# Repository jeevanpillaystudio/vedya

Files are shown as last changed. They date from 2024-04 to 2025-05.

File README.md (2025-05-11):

# Vedya Design System

A generative design system for creating and fabricating geometric patterns and modular structures with computational methods in Fusion 360.

## Overview

**Project:** Mandala Sculpture for Australia Bush Festival  
**Materials:** Wood (Huon Pine), Modelling Paste, 3D Print Materials, CNC Router Materials  
**Dimensions:** Full Installation 2m x 2m; Prototypes vary in size

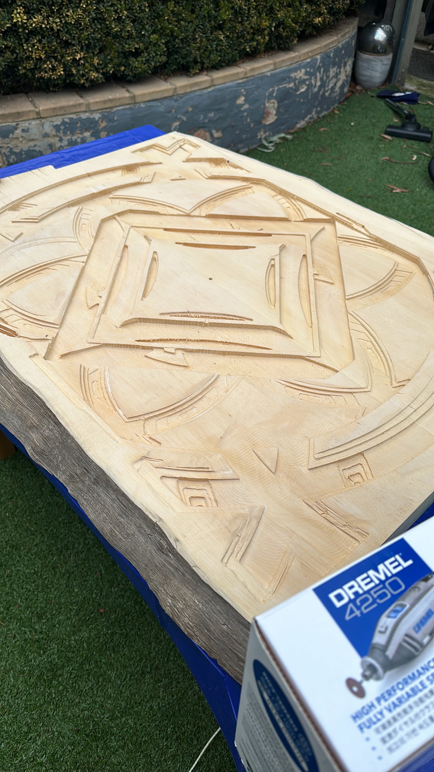
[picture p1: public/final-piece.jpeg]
Vedya Prototype

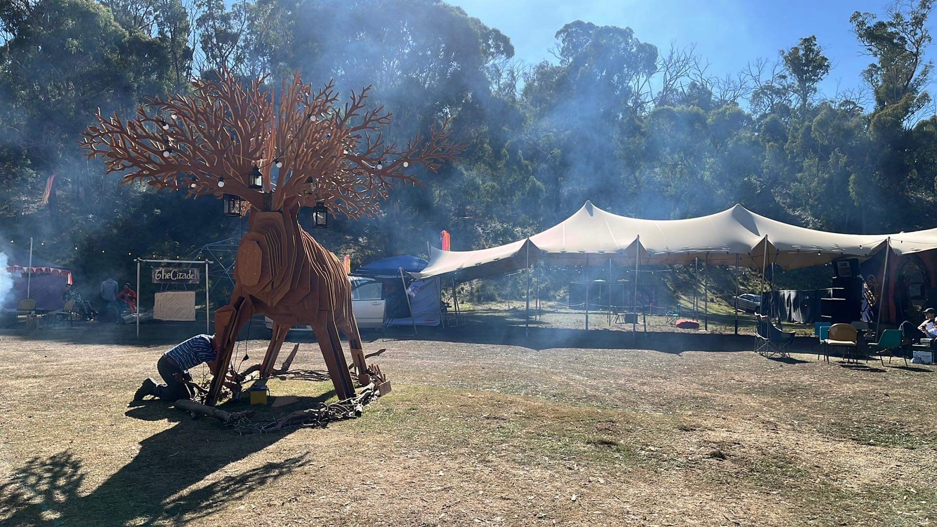
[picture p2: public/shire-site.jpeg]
Vedya on-site


## Visual Examples

### Fabrication Process
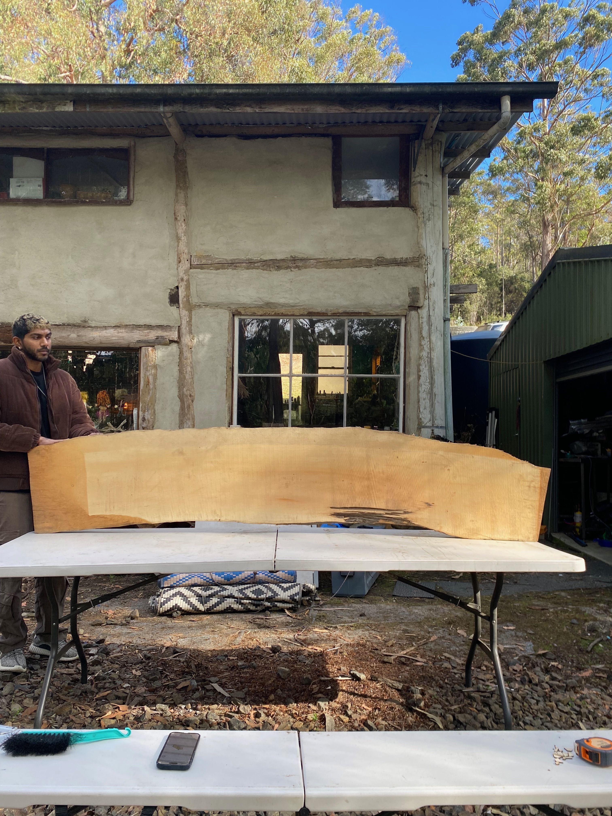
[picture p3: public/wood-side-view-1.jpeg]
Wood Source Material

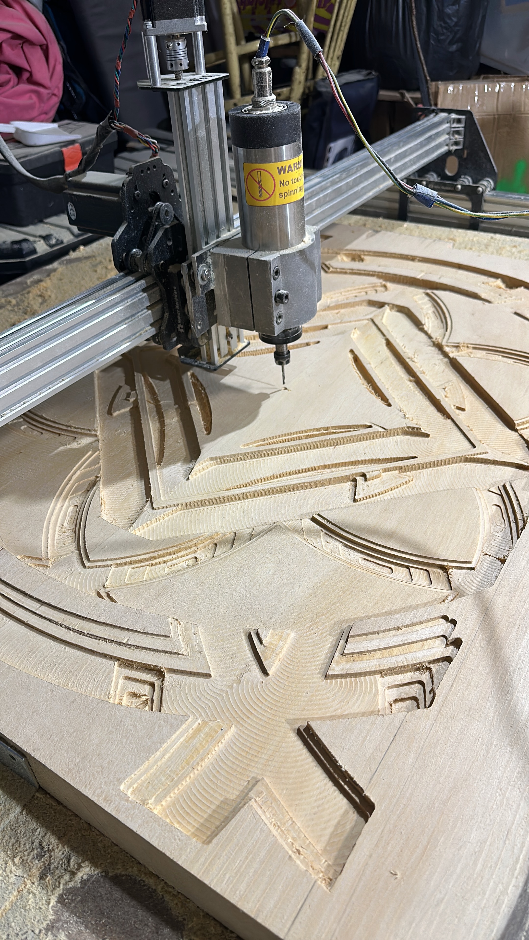
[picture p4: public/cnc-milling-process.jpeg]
CNC Milling Process


## Algorithm & Design Approach

The Vedya system uses a hierarchical composition-based algorithm to generate complex geometric designs:

### Core Algorithm

```
FUNCTION GenerateVedyaDesign(designType, seed, fabricationType, fabricationMode):
    // Initialize design context
    context = CreateDesignContext(designType, seed, fabricationType, fabricationMode)
    
    // Generate base geometry based on selected design template
    component = GenerateShireDesign(context.rootComponent)
    
    // Apply post-processing based on fabrication mode
    IF fabricationMode == "slicer":
        SliceComponent(component, layerDepth, layerCount)
    ELSE IF fabricationMode == "aggregator":
        AggregateComponents(component)
    
    RETURN component
```

### Composition System

The design generation uses a composition-based approach:

1. **Primitive Shapes**: Basic geometric elements (circles, rectangles)
2. **Modifiers**: Operations applied to shapes (extrude, boolean, array)
3. **Composition Layers**: Collections of shapes with modifiers
4. **Full Composition**: Hierarchical arrangement of layers

Example of the Shire design generation:

```
FUNCTION GenerateShireDesign(rootComponent):
    // Create background layer
    background = CreateBackgroundLayer(rootComponent)
    
    // Create border
    border = CreateBorder(rootComponent)
    
    // Create seed of life patterns (layered)
    seedOfLifeLayer0 = CreateSeedOfLifeLayer0(rootComponent)
    seedOfLifeLayer1 = CreateSeedOfLifeLayer1(rootComponent)
    seedOfLifeLayer2 = CreateSeedOfLifeLayer2(rootComponent)
    
    // Create core component
    core = CreateComponentCore(rootComponent)
    
    // Create torus astroid pattern
    torusAstroid = CreateTorusAstroid(rootComponent)
    
    // Apply middle cut
    ApplyMiddleCut(rootComponent)
    
    // Apply terrain cut (optional)
    ApplyTerrainCut(rootComponent)
    
    RETURN rootComponent
```

### Key Geometric Algorithms

#### Astroid Curve Algorithm

An astroid is a hypocycloid with four cusps. In the Vedya system, we implement a generalized version that allows for variable cusps (n-cusps) and parametric control. The algorithm to generate points along an astroid curve is:

```
FUNCTION GenerateAstroidPoints(centerX, centerY, radius, n, numPoints):
    points = []
    
    // Generate points along the astroid curve
    FOR i = 0 TO numPoints-1:
        t = i * (2π/numPoints)
        x = centerX + radius * cos(t)^n
        y = centerY + radius * sin(t)^n
        points.ADD((x, y))
    
    RETURN points
```

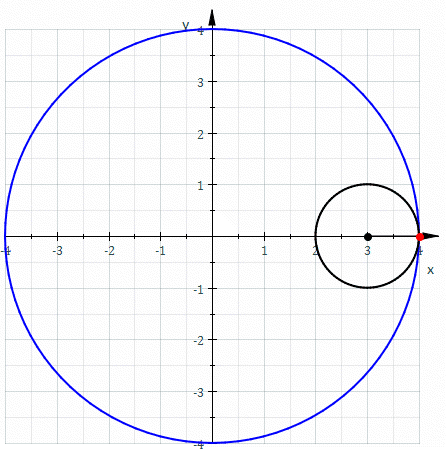
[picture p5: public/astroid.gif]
Astroid Curve Pattern


Where:
- `n` is the power parameter that controls the shape (n=3 for classic astroid)
- `numPoints` determines the resolution of the curve
- `radius` controls the size of the astroid

The Torus Astroid in the Vedya system combines this curve with circular elements to create complex patterns with:
- Inner and outer boundaries
- Stroke weight variations
- Radial symmetry
- Depth variations when extruded to 3D

#### Seed of Life Algorithm

The Seed of Life is a sacred geometry pattern formed by seven overlapping circles of the same size. The algorithm to generate this pattern follows these steps:

```
FUNCTION GenerateSeedOfLife(centerX, centerY, radius):
    // Create the central circle
    circles = [Circle(centerX, centerY, radius)]
    
    // Create six circles around the central circle
    FOR i = 0 TO 5:
        angle = i * (2π/6)
        newCenterX = centerX + radius * cos(angle)
        newCenterY = centerY + radius * sin(angle)
        circles.ADD(Circle(newCenterX, newCenterY, radius))
    
    RETURN circles
```

The Seed of Life pattern has deep historical significance in sacred geometry, appearing in ancient cultures worldwide. In the Vedya system, this pattern serves as a foundational element for creating complex mandala designs. The implementation allows for:

- Variable scaling of the pattern
- Layering with different radii
- Combination with other geometric elements through boolean operations
- Depth extrusion to create 3D forms

### Geometric Operations

The system uses several key geometric operations:

1. **Boolean Operations**: Union, difference, and intersection of shapes
2. **Array Patterns**: Radial, linear, and grid arrangements of elements
3. **Extrusion**: Converting 2D sketches to 3D forms
4. **Coordinate Transformations**: Mapping between coordinate systems (cartesian, cylindrical, spherical)

## Architecture

The Vedya system follows a pattern → transform → render workflow:
- **Pattern:** Generate base geometric patterns
- **Transform:** Apply coordinate transformations (cartesian, cylindrical, spherical)
- **Render:** Output to various formats (STL, OBJ, PNG)

## Setup & Installation

### Fusion 360 Integration

1. Configure environment:
   ```
   # In .env file
   PYTHONPATH=/path/to/fusion360/API/Python/libs
   LOGFILEPATH=/path/to/logfile.txt
   ```

2. Run the script:
   - Open Fusion 360
   - Open the script in Script Editor
   - Run the script

### Python Development

1. Setup environment:
   ```
   poetry shell
   poetry install
   ```

2. Available commands:
   ```
   # Transform coordinates
   vedya transform input.txt --target cylinder --resolution 0.1 --length 10 --height 4 --radius 1 --output output.txt
   
   # Render output
   vedya render output.txt --output output.stl --color grayscale
   
   # Run examples
   vedya example output_path
   ```

## Fabrication Methods

### 3D Printing
- **Printers:** Bambu Labs X1C/P1S (256mm³ build volume)
- **Materials:** PLA, PETG, TPU, ABS, ASA, PVA, PET
- **Examples:**
  - [Print 1 with Kailash Terrain](public/3d-printer-prototypes/print-1/3d-vedya-print-with-kailash-0.75;1;8.mp4)
  - [Print 2 Standard](public/3d-printer-prototypes/print-2/3d-vedya-print-1;1;8.mp4)
  - [Detailed Print Process](src/public/videos/detailed-print-process.mov)

### CNC Milling
- Used for wood components (Huon Pine)
- [Laser Prototype Slice](public/laser-prototypes/vedya-laser-1/slice-body-8/slice-body-8.stl)
- [CNC Toolpath Simulation](src/public/videos/cnc-toolpath-simulation.mov)

### Terrain Models
- [Low Resolution Kailash](public/low-res-kailash/low-res-kailash.stl)
- [Medium Resolution Kailash](public/mid-res-kailash/mid-res-kailash.stl)
- [Terrain Integration Process](public/terrain-integration.png)

## Project Components

### Shire
Mandala design for Australia Bush Festival, collaboration between Jeevan Pillay and Adam Brown, Gemma & team at Tasmania.
- Implementation: [Shire Design](src/core/fabrication/design/shire/index.py)
- [Installation Photos](public/shire-site.jpeg)

## Documentation

Additional documentation available in subdirectories:
- [Core Library Documentation](src/lib/README.md)
- [Print 1 Notes](public/3d-printer-prototypes/print-1/README.md)
- [Print 2 Notes](public/3d-printer-prototypes/print-2/README.md)

## Troubleshooting

- [Fixing VSCode x Python Code Hints](https://forums.autodesk.com/t5/fusion-api-and-scripts/code-hints-in-visual-studio-code-howto/td-p/9151250)
- [BambuStudio Filament Process](public/3d-printer-prototypes/README.md)

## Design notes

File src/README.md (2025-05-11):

# API Vedya Draw

A Fusion 360 add-in for generating parametric and direct designs using the Vedya design system.

## Overview

This add-in provides tools for creating generative designs within Fusion 360, with a focus on:
- Mandala-like patterns
- Modular storage systems (UMSS)
- Architectural models (Parthenon)

## Installation

1. Clone this repository to your local machine
2. In Fusion 360, go to **Scripts and Add-Ins** (Shift+S)
3. Click the green "+" icon next to "My Scripts"
4. Navigate to the cloned repository and select the `src` folder
5. Click "Run" to execute the script

## Configuration

### VSCode Setup

1. Install recommended extensions:
   - ms-python.black-formatter
   - ms-python.vscode-pylance

2. Configure Python paths in `.vscode/settings.json`:
   ```json
   "python.autoComplete.extraPaths": [
       "/path/to/Autodesk/Autodesk Fusion 360/API/Python/defs"
   ],
   "python.analysis.extraPaths": [
       "/path/to/Autodesk/Autodesk Fusion 360/API/Python/defs"
   ]
   ```

3. Set up debugging in `.vscode/launch.json`

## Project Structure

- `APIDrawVedya.py` - Main entry point for the Fusion 360 add-in
- `APIDrawVedya.manifest` - Add-in manifest file
- `__main__.py` - Standalone execution entry point
- `/core` - Core functionality
  - `/context.py` - Fusion 360 design context
  - `/types.py` - Type definitions
  - `/utils.py` - Utility functions
  - `/geometry` - Geometric primitives and operations
  - `/fabrication` - Fabrication-specific code
    - `/design` - Design templates
      - `/umss` - Universal Modular Storage System
      - `/parthenon` - Parthenon architectural model
      - `/shire` - Shire festival installation
- `/lib` - Standalone Python library for coordinate transformations and rendering

## Usage

The add-in creates designs based on the selected fabrication type and mode:

```python
# Example from APIDrawVedya.py
context = FusionDesignContext(
    app_context=adsk.core.Application.get(),
    design_type=DesignType.DIRECT,
    seed=create_seed(),
    fabrication_type=FabricationType.CNC_MILL,
    fabrication_mode=FabricationMode.NORMAL,
)

# Generate the design
start_func(root_component)
```

## Fabrication Types

- `CNC_MILL` - For CNC milling operations
- `PRINT_3D` - For 3D printing
- `LASER_CUT` - For laser cutting

## Fabrication Modes

- `NORMAL` - Standard design generation
- `SLICER` - Generates sliced layers for fabrication
- `AGGREGATOR` - Combines multiple components

## Examples

### UMSS (Universal Modular Storage System)

The UMSS is a modular storage system designed for 3D printing:
- Based on 128mm x 128mm tiles
- Uses CA007 (6x3mm) and CA008 (8x3mm) magnets
- Includes female/male tile pairs

See [UMSS Design](./core/fabrication/design/umss/index.py) for implementation details.

### Shire Festival Installation

A mandala-like design for the Shire festival in Victoria, Melbourne:
- Collaboration with Adam Brown, Gemma & team in Tasmania
- Uses Huon Pine wood
- Generated using a specific seed for consistency

See [Shire Design](./core/fabrication/design/shire/index.py) for implementation details.

## Library Tools

The `lib` directory contains standalone Python tools for:
- Coordinate transformations (cartesian, cylindrical, spherical)
- Rendering outputs to various formats
- Example generators

See [Library Documentation](./lib/README.md) for more details.

## Troubleshooting

1. [Fixing VSCode x Python Code Hints](https://forums.autodesk.com/t5/fusion-api-and-scripts/code-hints-in-visual-studio-code-howto/td-p/9151250)
2. If you encounter errors with Python paths, ensure your `.vscode/settings.json` points to the correct Fusion 360 API location
3. For logging issues, check the `logfile.txt` in the add-in directory

## Resources

- [Fusion 360 API Documentation](https://help.autodesk.com/view/fusion360/ENU/?guid=GUID-7B5A90C8-E94C-48DA-B16B-430729B734DC)
- [Python API Reference](https://help.autodesk.com/view/fusion360/ENU/?guid=GUID-9BAACC99-6666-4210-9F52-36D6A3275E5B)
- [3D Printing Prototypes](../public/README.md)

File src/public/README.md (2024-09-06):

## 3D Printer Prototyping
#### Model

| Model | Material Supported | Bed Size | Printer Size | Support | Sound Levels (dB) |
| --- | --- | --- | --- | --- | --- |
| Bambu Labs X1C | PLA, PETG, TPU, ABS, ASA, PVA, PET | 256mm x 256mm x 256mm | 389mm x 389mm x 457mm | Concrete Slab (450mm x 450mm) - Soft Foam | |
| Bambu Labs P1S | PLA, PETG, TPU, PVA, PET, ABS, ASA | 256mm x 256mm x 256mm | 389mm x 389mm x 457mm | Concrete Slab (450mm x 450mm) - Soft Foam | |
> for knowledge base, head [here](https://wiki.bambulab.com/en/knowledge-sharing)

### UMSS Tiling

#### Milestone 1 - 6x3 N35 Magnet (without fillet)	
| Hole Radius (mm) | Fitting | Notes |
| --- | --- | --- |
| 0.30 | Tight | |
| 0.31 | Perfect | Slight force needed to push it in but fits in tightly. Removing magnet can be an issue though. |
| 0.32 | Slightly Loose | |
| 0.33 | Loose | |
| 0.34 | Loose | |
| 0.35 | Loose | |

#### Milestone 2 - 6x3 N35 Magnet with 0.31mm Hole (with fillet)	
| Fillet Size (mm) | Fitting | Notes |
| --- | --- | ----- |
| 1 | Perfect | |
| 1.25 | Perfect | |
| 1.5 | Slightly Loose | |
| 1.75 | Slightly Loose | |
| 2 | Slightly Loose | |
#### Milestone 3
> built grid of tiles; 5 by 5 with thickness of 1mm; r.e printed two version. 
> 1. full grid 5 by 5
> 2. only the corners (meaning a cut-out in the middle) - save material
#### Milestone 4
> built with wall thickness 1.28mm, outer wall thickness of 5mm (stroke-weight 1.28mm), inner cross-section wall of 4mm (stroke-weight 0.96mm)

#### Essentials
1. https://youtu.be/J_pxk7HP3RE?si=55Y-H1U8Oew2n4SE
2. [Concrete Slab + Foam Sound & Vibration Dampening](https://youtu.be/y08v6PY_7ak?si=_SXhxkkFH9TeksmH)

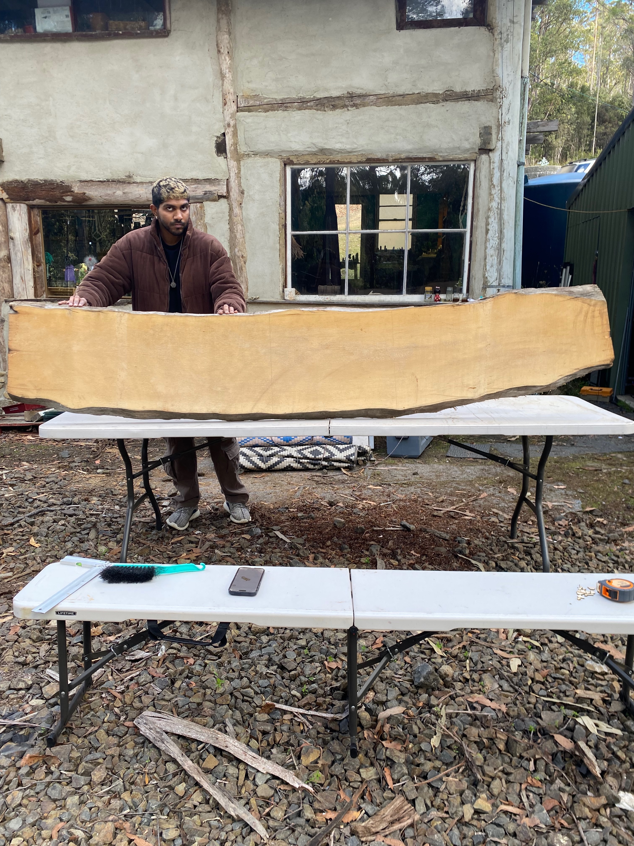
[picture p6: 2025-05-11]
public/wood-side-view-2.jpeg

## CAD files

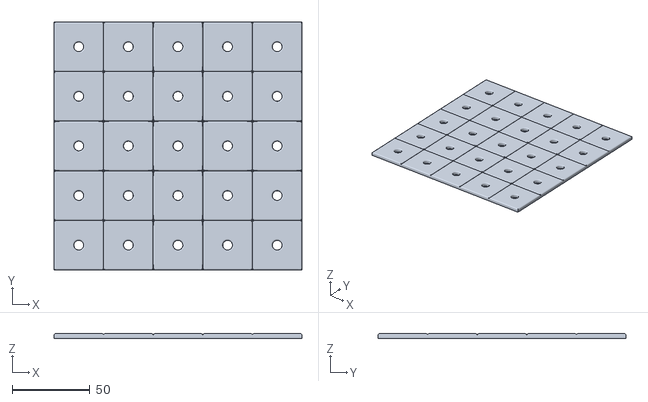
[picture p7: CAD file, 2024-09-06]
src/public/f360-milestone-3/5by5-full.stl
160.0 x 160.0 x 3.00

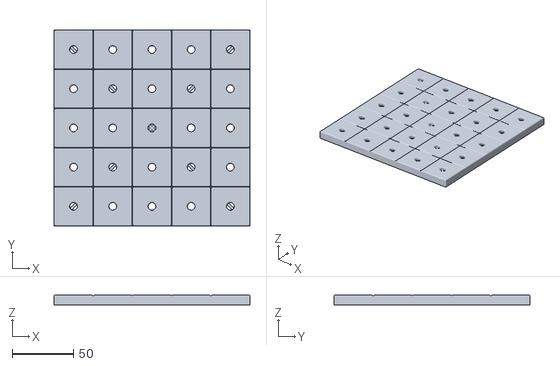
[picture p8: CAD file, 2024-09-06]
src/public/f360-milestone-4/5by5-full-with-brace.stl
160.0 x 160.0 x 8.00

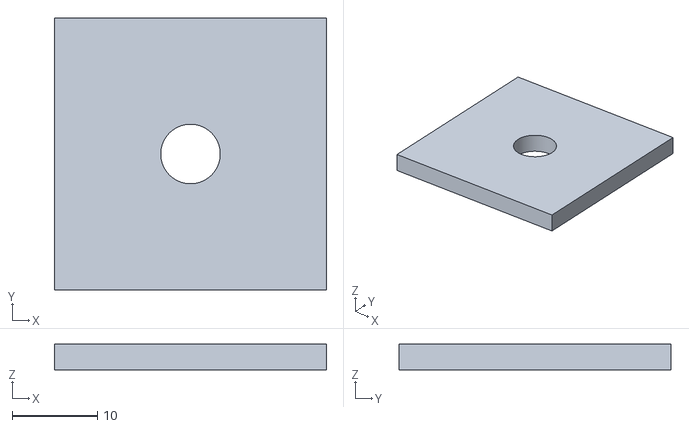
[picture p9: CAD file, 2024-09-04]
src/public/f360-milestone-1/tile-magnet-hole-radius-0.35mm.stl
32.0 x 32.0 x 3.00

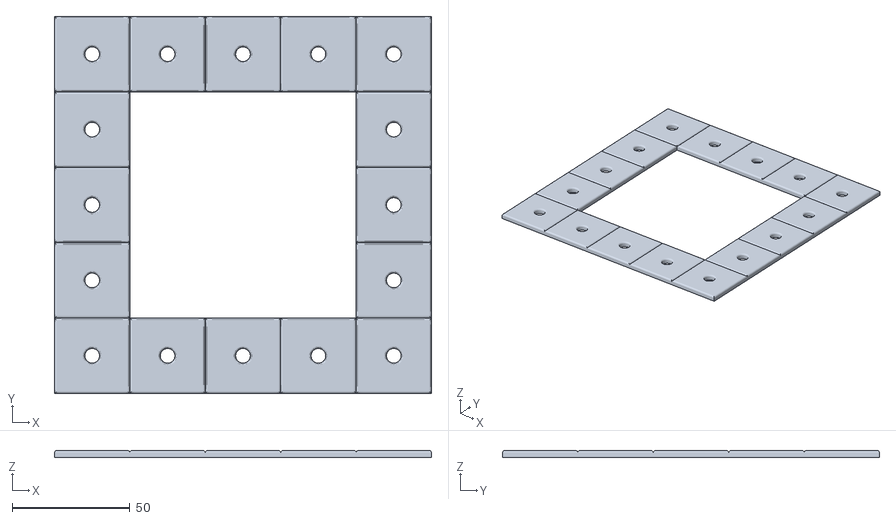
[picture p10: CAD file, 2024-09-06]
src/public/f360-milestone-3/5by5-only-corner.stl
160.0 x 160.0 x 3.00

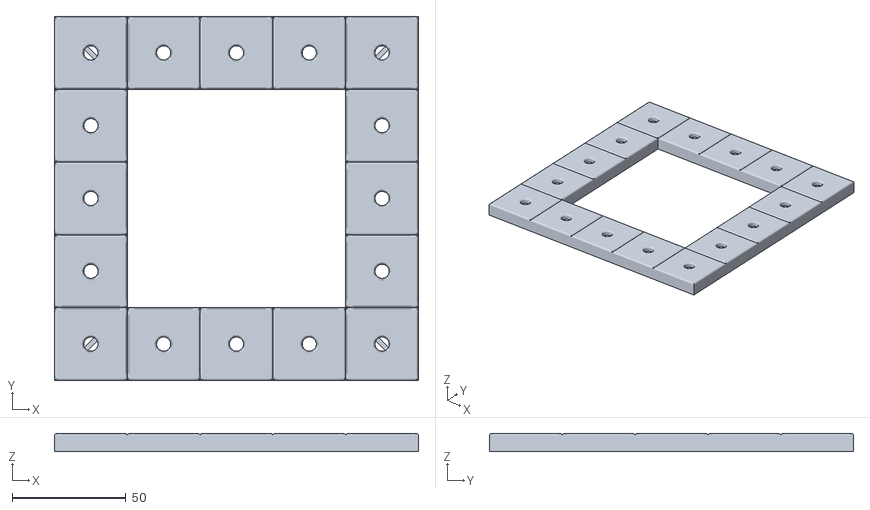
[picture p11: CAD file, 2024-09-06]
src/public/f360-milestone-4/5by5-only-corner-with-brace.stl
160.0 x 160.0 x 8.00

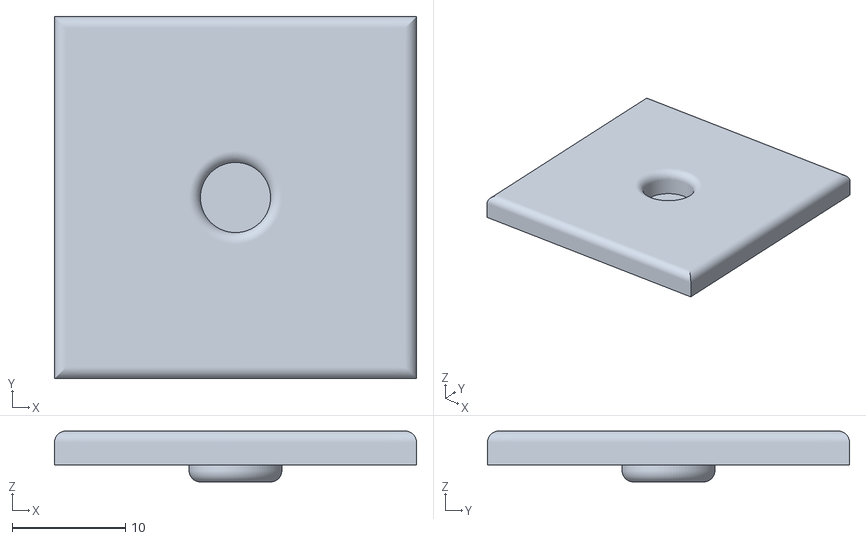
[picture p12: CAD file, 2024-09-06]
src/public/f360-milestone-5/magnet-base-ring-thickness-0.15mm.stl
32.0 x 32.0 x 4.50

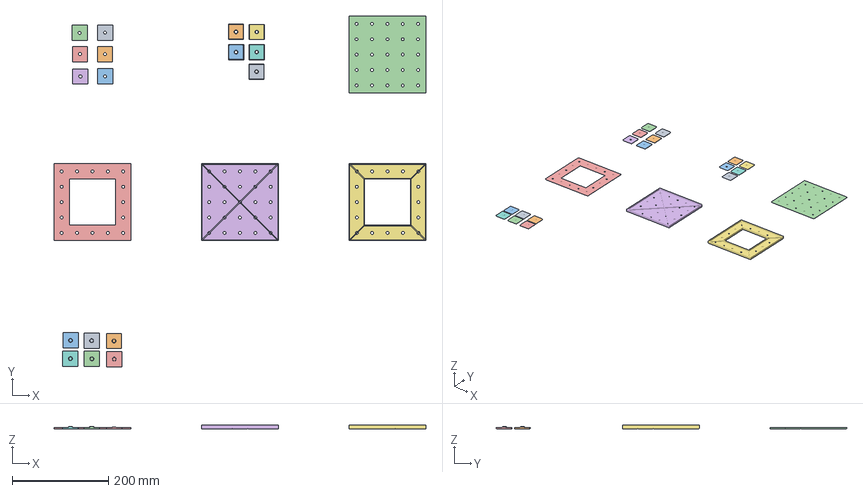
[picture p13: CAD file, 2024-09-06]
src/public/tile-magnet-hole-radius-0.30mm.3mf
774.2 x 729.7 x 8.00 mm
tile-magnet-hole-radius-0.30mm.stl
tile-magnet-hole-radius-0.31mm.stl
tile-magnet-hole-radius-0.32mm.stl
tile-magnet-hole-radius-0.33mm.stl
tile-magnet-hole-radius-0.34mm.stl
tile-magnet-hole-radius-0.35mm.stl
tile-magnet-fillet-1mm.stl
tile-magnet-fillet-1.25mm.stl
tile-magnet-fillet-1.5mm.stl
tile-magnet-fillet-1.75mm.stl
tile-magnet-fillet-2mm.stl
5by5-full.stl
5by5-only-corner.stl
5by5-full-with-brace.stl
5by5-only-corner-with-brace.stl
magnet-base-ring-thickness-0.25mm.stl x 2
magnet-base-ring-thickness-0.20mm.stl x 2
magnet-base-ring-thickness-0.15mm.stl x 2

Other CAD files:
public/3d-printer-prototypes/print-1/3d-vedya-print-0.75;1;8.3mf
public/3d-printer-prototypes/print-2/3d-vedya-print-1;1;8.3mf
public/laser-prototypes/vedya-laser-1/slice-body-4/slice-body-4.stl
public/laser-prototypes/vedya-laser-1/slice-body-5/slice-body-5.stl
public/laser-prototypes/vedya-laser-1/slice-body-6/slice-body-6.stl
public/laser-prototypes/vedya-laser-1/slice-body-7/slice-body-7.stl
public/laser-prototypes/vedya-laser-1/slice-body-8/slice-body-8.stl
public/laser-prototypes/vedya-laser-1/slice-body-9/slice-body-9.stl
public/low-res-kailash/low-res-kailash.stl
public/mid-res-kailash/med-res-kailash.obj
src/public/f360-milestone-2/tile-magnet-fillet-1mm.stl
public/3d-printer-prototypes/3d-print.f3d
public/3d-printer-prototypes/print-1/3d-vedya-print-0.75;1;8.stl
public/3d-printer-prototypes/print-1/3d-vedya-print-with-kailash-0.75;1;8.stl
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

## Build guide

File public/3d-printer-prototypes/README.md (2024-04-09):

### Helpers

1. Access BambuStudio Filament Process
    - /Users/[username]/Library/Application Support/BambuStudio/user

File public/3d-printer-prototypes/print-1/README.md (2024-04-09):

# Information

1. Failed due to wrong `wall generator` settings; `classic` was selected on Bambu Labs.
2. Kailash terrain printed decently.

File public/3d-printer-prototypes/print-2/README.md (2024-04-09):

# README

1. `Wall Geneator` settings; `arachne` was selected on Bambu Labs.

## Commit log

2024-04-03 added blender, stl & obj file
    [low-res-kailash.blend, low-res-kailash.obj, low-res-kailash.stl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]
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2024-04-08 added lfs & 3d-print-prototypes
    [3d-vedya-print-0.75;1;8.3mf, 3d-vedya-print-0.75;1;8.stl, 3d-vedya-print-with-kailash-0.75;1;8.stl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]
2024-04-08 added f3d main file
    [3d-print.f3d]
2024-04-09 added 3d printer mods folder
    [3d-print.f3d, 3d-vedya-print-0.75;1;8.3mf, 3d-vedya-print-0.75;1;8.stl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]
2024-04-09 added vedya print two, same issue; can see in bambu studio, slice plate only shows some parts of the print
    [3d-vedya-print-0.75;1;8.3mf, 3d-vedya-print-0.75;1;8.stl, 3d-vedya-print-with-kailash-0.75;1;8.stl]
2024-04-09 added print-2 details and updated README for print-1
    [3d-print.f3d, 3d-vedya-print-0.75;1;8.3mf, 3d-vedya-print-1;1;8.3mf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]
2024-04-09 added user profile
    [3d-vedya-print-1;1;8.3mf]
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2024-04-09 updated 3d-print.f3d
    [3d-print.f3d]
2024-04-09 added kailash print-2
    [3d-print.f3d, 3d-vedya-print-with-kailash-0.75;1;8.stl]
2024-04-09 added kailash to bambu studio
    [3d-vedya-print-1;1;8.3mf]
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2024-04-10 added torus
    [3d-vedya-print-1;1;8.3mf]
2024-04-10 added timer system & now instead of drawing many sketches, the body just gets copied and move
2024-04-10 reintroduced kailash cut on seed of life; not working
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2024-04-17 current version; kinda broken
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2024-04-17 added laser prototypes stl & dxf file (for lightburn)
    [slice-body-4.dxf, slice-body-4.stl, slice-body-5.dxf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]
2024-04-18 added lidar scan results of prototype wood
    [slice-body-4.dxf, slice-body-4.stl, slice-body-5.dxf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]
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2024-04-21 now sol generates first; issue with cut
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2024-06-08 now the full transformation of a circle to a cylinder has been written in matplotlib
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2024-07-17 added bse files for cylinder transform and openscad file gen
    [cylindrical_model.scad]
2024-07-17 fixed issue with coord-transform not running; the cylinder_resolution in __main__ was too high
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2024-07-18 created components that mimic cylinder & rectangles; being drawn out looking like wireframes using points & buffer
2024-07-20 now viewcube & stl objects moves together
    [teapot.stl]
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2024-08-19 moved vedya files to v1 folder
    [3d-print.f3d, 3d-vedya-print-0.75;1;8.3mf, 3d-vedya-print-0.75;1;8.stl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]
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2024-08-20 added kailash terrain cut to shire; not cutting due to area hard coded
2024-08-20 fixed all arguments in func to snake case
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2024-08-24 somewhat union & difference working; issue is that we only work on single BRepBody when sometimes there can be multiples after a cut
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2024-08-27 removed unused python related stuff
    [cylindrical_model.scad]
2024-08-27 created public fodler for v1
    [3d-print.f3d, 3d-vedya-print-0.75;1;8.3mf, 3d-vedya-print-0.75;1;8.stl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]
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2024-09-04 f360 milestone 1; raidius variation
    [tile-magnet-hole-radius-3.0.stl, tile-magnet-hole-radius-3.1.stl, tile-magnet-hole-radius-3.2.stl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]
2024-09-04 converted the magnet hole stl files to mm
    [tile-magnet-hole-radius-0.30mm.stl, tile-magnet-hole-radius-0.31mm.stl, tile-magnet-hole-radius-0.32mm.stl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]
2024-09-04 seems like 0.31mm is a perfect fit. but still slightly tight. now lets do testinggg on fillet
    [tile-magnet-hole-radius-0.30mm.3mf, tile-magnet-hole-radius-mm-test.3mf, tile-magnet-hole-radius-mm-test.f3d]
2024-09-06 added all milestone prints; 1 - 4
    [5by5-full-with-brace.stl, 5by5-full.stl, 5by5-only-corner-with-brace.stl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]
2024-09-06 added milestone 5
    [magnet-base-ring-thickness-0.15mm.stl, magnet-base-ring-thickness-0.20mm.stl, magnet-base-ring-thickness-0.25mm.stl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]
2025-05-11 removed all files related to the 3D printer prototypes and laser prototypes, including various STL, OBJ, and other format files, as well as associated README and configuration files
    [3d-print.f3d, 3d-vedya-print-0.75;1;8.3mf, 3d-vedya-print-0.75;1;8.stl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]
2026-10-14 Add the uv project scaffold
    The project metadata and tool configuration for the build123d rewrite:
    pyproject.toml (uv_build backend, dependencies, the render extra, ruff,
    pyright strict, pytest and coverage settings), a Makefile whose default
    target is `check`, pre-commit hooks that run ruff and `uv lock --check`
    through uv, an .editorconfig, a CI workflow with a lint job and a test
    matrix, Dependabot for uv and GitHub Actions, and a .gitignore cut down
    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
2026-10-14 Keep the checks off the Fusion 360 code until it leaves the tree
    The old script stays in src/ until its replacement passes, and nothing
    reads it from the working tree: the behaviour pin reads it from git
    history. Linting it would mean 474 ruff findings and 399 pyright errors
    in code that is about to go, and pre-commit's whitespace fixers would
    rewrite files, src/public/ among them, that are later moved by blob id.
    - ruff excludes the Fusion code, and force-exclude applies that to the
    files pre-commit names.
    - pyright checks src/vedya rather than all of src.
    - pre-commit skips src/ outside src/vedya, .vscode/ and .env.example.
    - The whitespace hook keeps Markdown's two-space line breaks.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
2026-10-14 Add the geometry, model and export layers of the vedya package
    The package starts as a uv project on Python 3.12, with the lock file
    and the `examples` extra (noise 1.2.2, for the flow field to come).
    - geometry: circle, rectangle and diamond regions; `stroke`, the band
    along an outline on the side `Align` names (INSIDE is Fusion's Side1),
    offset with sharp corners; and `slab`, a region swept from z upwards.
    `Region` names what build123d's operators are typed to return.
    - model: `Model`, a design's named parts in build order and read-only;
    `aggregate`, their fusion; and `fingerprint`, the volume, area,
    bounding box and centroid the goldens will hold.
    - export: STEP and STL by file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
2026-10-14 Build UMSS from the vedya command line
    - designs: `Design(name, params, build)` and `load_designs()`, which
    reads the `vedya.designs` entry-point group. The package registers its
    own designs there too, so there is one way in.
    - designs/umss: `UmssParams` and `build`. The default builds the magnet
    base disc the Fusion script built last (r 3.1, h 1.5, z -2.5);
    `parts=("tile",)` builds milestone 1's tile with its through hole, and
    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
2026-10-14 Run the 2024 Fusion 360 scripts from history on a stand-in for Fusion
    tools/legacy/adsk stands in for Autodesk's adsk package, on build123d, in
    centimetres, with only the API members UMSS's scripts call: components,
    offset planes and sketches, circles and two-point rectangles, profiles,
    full and thin extrudes, and combine. It behaves as the milled model shows
    Fusion behaved:
    - Profiles are the closed regions the sketch's curves bound, with their
    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
2026-10-14 Pin UMSS to what HEAD's Fusion script builds, and check the stand-in in CI
    tests/golden/umss.json is HEAD's script (08f31da) run on the stand-in: one
    top-level component, the magnet base, 45.2860581 mm3, from z -2.5 to -1.0
    mm. `make golden` rewrites it, with the source commit and build123d's
    version. test_umss.py holds the default build to it, at a relative 1e-6 in
    volume and area and 1e-3 mm in bounds and centroid.
    The slow tests run the scripts from history. The milestone-1 scripts at
    af36f97 and de4e698 give tiles 0.0850 and 0.0865 mm3 smaller than
    Fusion's STL files, inside the band the six files measured, with
    equal bounding boxes. The golden is rebuilt and compared, and a failure
    the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
2026-10-14 Draw an astroid as Fusion fitted it, and aggregate copies of the parts
    geometry.astroid(radius, points=128) is the cubic spline through
    points + 1 samples of radius * (cos^3, sin^3), at 2*pi*i/points, written
    as the Fusion 360 script wrote them: not periodic, and closed because
    its ends meet. The spline rounds the cusps, so its area is (3/8)*pi*r^2
    less a relative 9.1943e-7 at every radius; test_geometry holds it there
    over radii, and checks it passes through its samples, keeps its cusps on
    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
2026-10-14 Pin Shire to what a36cc3c's Fusion script builds
    tests/golden/shire.json is a36cc3c's src/v1/api-vedya-draw run on the
    stand-in, in mm: the eight top-level parts in the order the script
    builds them (bg, border, layer-0, layer-2, layer-1, core, torus,
    middle-ring) and the aggregate the script joins them into, 17370265.03
    mm3. Every area pick in the run resolves to exactly one region. `make
    golden` rewrites it byte for byte.
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2026-10-14 Check Shire against the toolpaths it was milled from; it fails today
    tests/test_toolpaths.py reads public/cnc-cuts/6mm-adaptive.tap and
    3mm-adaptive.tap: G90 lines and arcs with centres relative to their
    start (G91.1), helical, in the XY plane and once in XZ (G18), G28
    leaving the axes it names unknown. It samples every move each 0.25 mm.
    The model less the border becomes a z-buffer height map at 0.5 mm, from
    its horizontal faces meshed to an absolute 0.01 mm (build123d's own
    tessellate takes its tolerance relative to each edge, which put chords
    across the 440 mm rings). Every position below z = 0 must have no model
    cell centre within the tool's radius higher than its tip + 0.15 mm,
    with the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
2026-10-14 Join stacks of slabs band by band in aggregate
    OpenCascade's 3D fuse fails where a thin wedge of one part, an astroid's
    cusp, lies inside another part whose level face crosses it. With Shire's
    core and layer-1 the fused solid kept the wedge's faces inside it: valid,
    but enclosing the wedge twice, 35 mm³ and 7 mm² of flats too large. With a
    stepped ring it dropped a quarter of a million mm³.
    Where every part is a stack of prisms along z, aggregate now cuts z into
    bands at the parts' level faces, joins the parts' sections in the plane,
    and glues the bands' slabs, which meet only at level faces. A section
    comes from the part's level faces when their edges are exact; a part a 3D
    boolean left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
2026-10-14 Let the toolpath test allow 0.1 mm sideways at walls
    Material under the tool counts only where it stands more than 0.1 mm
    inside the edge of the tool's circle. CAM brings the tool to a wall
    within its own cutting tolerance; the deepest graze measured is 0.065 mm.
    0.1 mm stays an order of magnitude below 1.2 mm, the shallowest step of a
    seed-of-life layer. The vertical allowance stays 0.15 mm.
2026-10-14 Join every part's slabs band by band, through one union in vedya.model
    vedya.model.union(parts) is the banded union that aggregate used, now
    public, and aggregate calls it. Shire's seed-of-life layers, core and
    torus join their slabs through it instead of a 3D fuse.
    The 3D fuse of the core's overlapping astroid slabs left edges and
    vertices 0.393 mm loose where the inner astroid meets z = 16.8, and the
    aggregate built from it carried 8.2e-4 mm. Through union every Shire
    part and the aggregate is at most 1.0e-7 mm, every golden still
    matches, and Shire builds in about 12.6 s instead of 26.5 s.
    A new test holds every part and the aggregate of every registered
    design, and of UMSS with all its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
2026-10-14 Write 3MF, meshed to the same absolute tolerance as STL
    export now writes .3mf beside .stl and .step/.stp. build123d's Mesher
    meshes a copy of the shape with a tolerance relative to each edge's
    size, so the shape is meshed here at 0.01 mm and 0.1 rad, as for STL,
    its corners welded where they are equal in single precision, and the
    mesh handed to lib3mf through the model Mesher sets up, in millimetres.
    Where two pieces of a solid touch along a line, four of its faces meet
    there, and four triangles at each side along it. Shire's aggregate has
    38 such edges, on the circle of 360 mm at z = 28.8, where layer-0 below
    and layer-2 above meet only along the arc. Around each such side the
    triangles a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
2026-10-14 Build the parts, the aggregate and its layers from the command line
    vedya build DESIGN now takes --parts, --aggregate and --slice H:N, and
    --format names stl, step and 3mf. --slice writes the aggregate cut into
    layers H mm high from the bottom up, at most N cuts, as
    <design>-slice-<i> from 0 at the bottom, the last being what is left
    above the last cut; a layer with nothing in it is skipped with a
    warning. With none of the three it writes the parts and the aggregate,
    as before, so make designs is unchanged. A --slice that is not
    HEIGHT:COUNT, or whose height or count is not positive, fails in one
    line before anything is built.
    build shire --aggregate --slice 3.2:12 writes 13 files per forma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
2026-10-14 Port the standalone library as tested functions behind vedya map, stencil and flowfield
    The 2024 library in src/lib opened windows and wrote placeholders. Its three parts
    become modules that return values, and the command line writes them to files, with
    the values the library fixed as defaults:
    - vedya.mapping: the maps to and from a cylinder and a sphere, on arrays of points,
    and the rectangle and disc samplers they carried. `vedya map cylinder|sphere`
    writes the points as CSV, and with --figure as a 3D figure in HTML.
    - vedya.render: stencil(image), the OpenCV pipeline step for step, returning the
    image; point_cloud_figure(...), returning the plotly figure. `vedya stencil`.
    - vedya.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
2026-10-14 Hold the Perlin noise to one single-precision step across platforms
    noise 1.2.2 gives pnoise2(0.1, 0.2, ...) as 0.07723968476057053 on Apple silicon and
    0.07723967730998993 on x86-64, in CI's Linux jobs on Python 3.12 to 3.14 and its
    Windows job: 2**-27 apart, one step of single precision. noise computes in single
    precision, and the compiler for Apple silicon fuses a multiplication and an addition
    into one rounding; built there with -ffp-contract=off, it gives the x86-64 value to
    the bit. The test now allows that one step, and says why; the flow field's docstring
    says its bit-for-bit match with the 2024 library holds for the same build of noise.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
2026-10-14 Document the repository: README, CONTEXT.md, three ADRs and AGENTS.md
    - README.md is rewritten for a newcomer: what Vedya is, Shire's story and
    credit line, the photograph, uv sync, vedya list and build, slicing and
    formats, the library's three commands, make check / slow / golden /
    designs, where the goldens come from, the three fusion/ tags, and the
    Licence section.
    - CONTEXT.md holds the domain words from the design discussion, corrected
    for the build: the reach rule, seed-of-life layers whose later pass trims
    the earlier, the stand-in's stacks, and the torus that adds no relief.
    - docs/adr/0001 build123d in millimetres; 0002 the pin by a stand-in that
    runs the 2024 scripts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
2026-10-14 Cut Shire's layer-0 to the board by default, and keep the pin on the 2024 build
    The 2024 script drew layer-0's circle, of radius 360 mm, on a board 640 mm
    wide, so its model overhung the board's long sides by up to 40 mm, which the
    milled board could not hold. ShireParams gains clip_to_board, True by default,
    which intersects layer-0's mask with the board, as layer-2's already is.
    clip_to_board=False builds the 2024 model exactly, overhang included.
    The pin stays on the 2024 build. The golden tests and the slow comparisons
    with the stand-in (each part's and the aggregate's XOR volume) use two new
    session fixtures, shire_unclipped and its aggregate. The unclipped model
    reuses the default bui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
